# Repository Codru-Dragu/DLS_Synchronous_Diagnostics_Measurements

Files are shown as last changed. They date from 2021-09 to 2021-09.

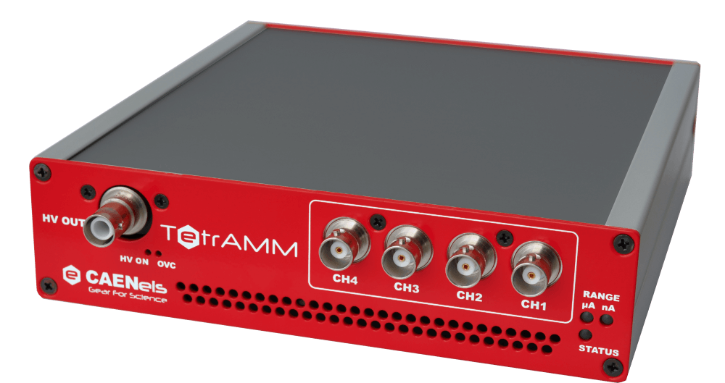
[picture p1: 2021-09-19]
Software Package/src/TetIMG.png

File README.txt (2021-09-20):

READ ME FILE for X-Ray Diagnostics Triggering system ofr DLS Diagnostics Team
Created by Summer Student 2021, Codrutza Dragu, University of Oxford

The hardware and software elements of the trigger are in their respective foler. A PDF help guide to both is located in the main directory, with the order of the GUI execution and what each file does. A general overview of the project is as given below:

This project is centered around helping the Diagnostics team acquire better data during their beamline vibrations analysis. This is done through a two-fold system, consisting of a ‘button-press’ hardware element to synchronously trigger the diagnostics hardware on the beamline, and a software package to fix any issues during data acquisition, and provide a user-friendly analysis interface. The system was tested on the i18 beamline in late June, and approximately 7hours worth of synchronous data was acquired and analyzed. The graphs produced at the end of the experiment indicate possibly uncorrelated vibrations coming from the horizontal focusing mirrors closest to the sample.

An issue many beamlines face, and one that affects the quality of the data acquired on the beamline, is if there are significant unwanted vibration present during beam time. These vibrations could be internal and come from the optical elements along the beamline, or from elements in the ring. They could even be external and come from overhead motion or from the air conditioning system. Identifying the source of unwanted vibration is critical in maintaining the quality of the beamline and the stability of the beam. Use of the diagnostics hardware present on the beamline allows data to be taken at beamline positions, and compared to determine whether there is uncorrelated motion present between the different acquisition devices, and if so, then further identification of the component causing the vibration. To accurately determine non-correlated motion, data should be acquired synchronously across all the hardware. The current limitation is that the EPICS interface controlling the hardware allows only manual acquisition for each hardware, and has no way to coordinate grabbing data from multiple hardware at the same time. The scope of this project is to produce a physical trigger system to control the hardware, and a software package that allows the trigger experiment to be monitored and has post-experiment Fourier analysis capabilities. 

The User Manual is porvided as the 'Help Guide' file and provides intructions and information about both the hardware and software packages.
More information and the results of the data anlysis from the i18 beamline experiemnt is available in the SummerStudent 2021 report document

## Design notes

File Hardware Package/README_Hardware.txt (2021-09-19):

This is the hardware portion of the project. It consits of the codes for a sender (Userside Arduino) and reciever (Midbox Arduino) as well as enclosures for the circuits required

STL for Trigger Enclosure Summary:
	
1 x UserSide_Box - the box for the control room arduino
	
1 x Midbox_Box - the box for the midbox arduino

1 x MidBox_Lid - lid for midbox box
	
1 x UserSide_Lid - lid fo userside box
	
1 x Userside_Cableholder - to secure the ethernet cable from the userside arduino box

4 x Midbox_Clip - Spacers to mount the midbox box. Print 2 extra (2+2) in case there are any drilling mishaps
	
1 x CamAdapt  - Adaptor for the Manta cam. Print for however many cameras there are. In our experiment, there was 1

2 x ActualTetAdapt - Adaptor for the Tetramm. Print for however many cameras there are. In our experiment, there waere 2
	
3 x Adapt_Lid - Lid for the TetrAMM and Camera Adaptor Boxes. Print for however many boxes there are. In our experiment, there were 3

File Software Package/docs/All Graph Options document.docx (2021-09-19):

All Graph options document

# Options Values

# Analysis Options:

# 0: DFT

# 1: CSP

# 2: CSP Normalised (Relative)

# Graph Options:

# 0: Plot X graph

# 1: Plot Y graph

# 2: Plot both X and Y graphs on the same plot

# Hardware options

# 0: A specific hardware - will be prompted to put the hardware name as well

# 1: A few select hardware - will be prompted to select which ones

# 2: All the hardware available

# Capture options

# 0: A specific capture - will be prompted to put which file is wanted

# 1: A range of captures unaveraged - will be prompted to put the range of files wanted

# 2: A range of captures averaged - will be prompted to put the range of files wanted

# 3: All files (this comes averaged by default)

# 4: All files average ONLY

# Stacked options

# 0: nonstacked

# 1: stacked

Different Graph Options and Corresponding Graph types:

(Alphabetical indexing scheme used in the Analysis_Grapher.py code file, and when deciding the kind of graph specified by the user checkbox options in Set_Up_Diagnostics_Hybrid.py)

A – Single Plot, Single Position, Single Hardware

B – Single Plot, Single Position, Multiple Hardware

C – Single Plot, Double Position, Single Hardware

D – Single Plot, Double Position, Multiple Hardware

E – Multiple Plot, Single Position, Single Hardware (DOES NOT EXIST)

F – Multiple Plot, Single Position, Multiple Hardware

G – Multiple Plot, Double Position, Single Hardware

H – Multiple Plot, Double Position, Multiple Hardware

Graph Display Options Based on Checkbox Choice

Analysis Options | Graph Options | Hardware Options | Stacked Option | Capture Options:
| | | | 0 (one capt) / 4 (only average displayed) | 1 (range) | 2 (range avg) | 3 (all)

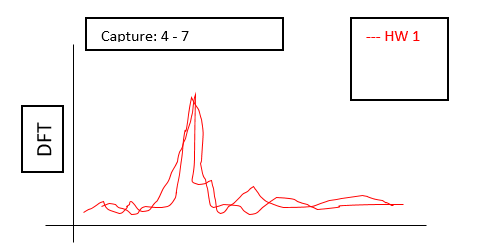
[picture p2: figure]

0 (DFT) A | 0 (x) 1 (y) (could be either) | 0 (1 hw) | 0
0 (DFT) | 0 (x) 1 (y) (could be either) | 0 (1 hw) | 1 | X | X | X | X

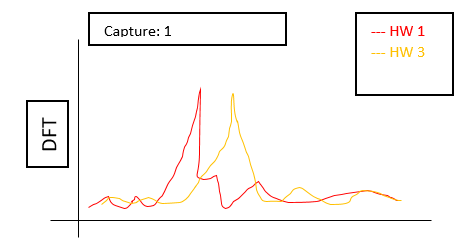
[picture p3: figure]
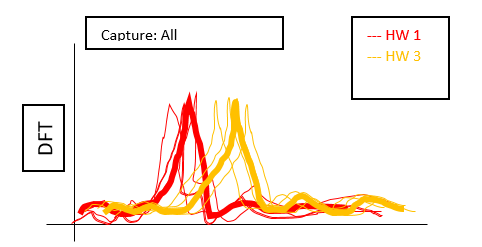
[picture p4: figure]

0 (DFT) B | 0 (x) 1 (y) (could be either) | 1 (more hw) | 0

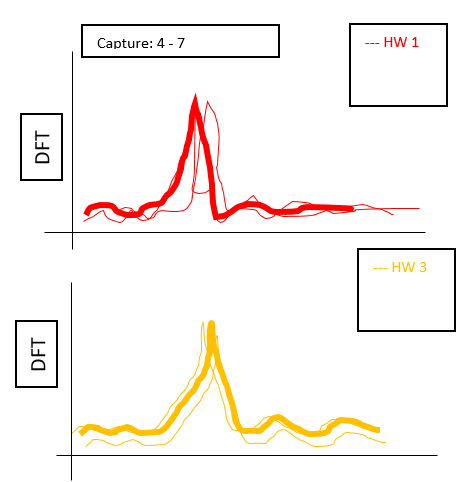
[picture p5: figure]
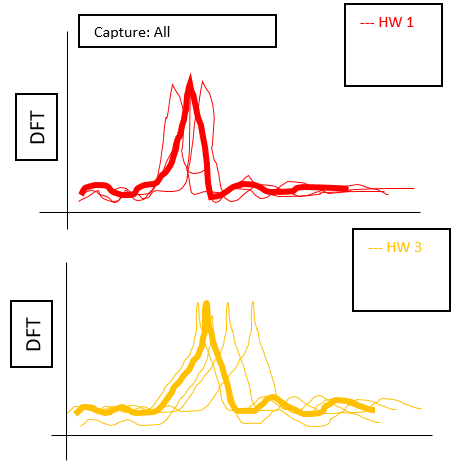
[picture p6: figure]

0 (DFT) F | 0 (x) 1 (y) (could be either) | 1 (more hw) | 1

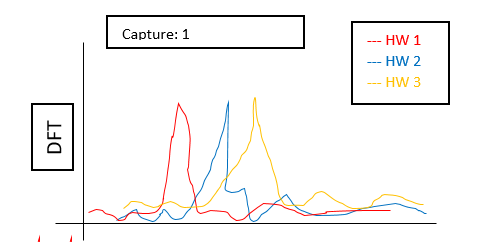
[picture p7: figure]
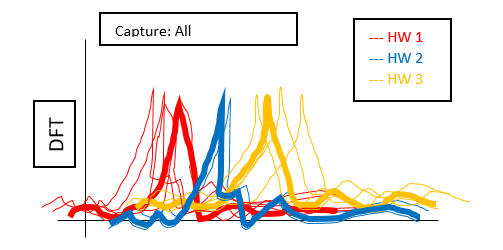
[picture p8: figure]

0 (DFT) B | 0 (x) 1 (y) (could be either) | 2 (all hw) | 0

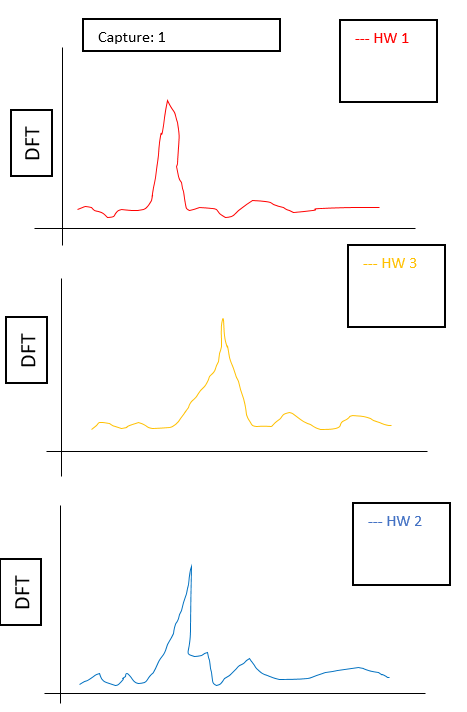
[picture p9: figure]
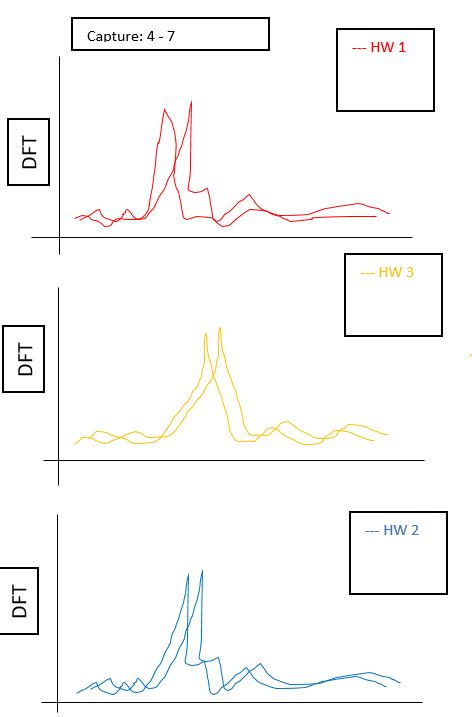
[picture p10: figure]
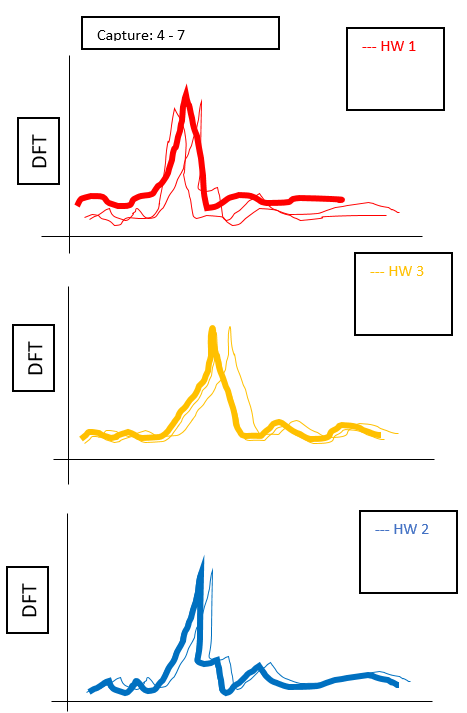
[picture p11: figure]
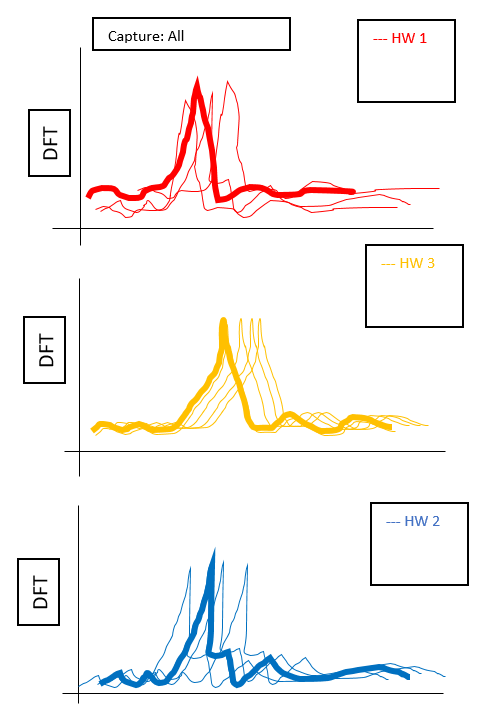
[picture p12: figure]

0 (DFT) F | 0 (x) 1 (y) (could be either) | 2 (all hw) | 1

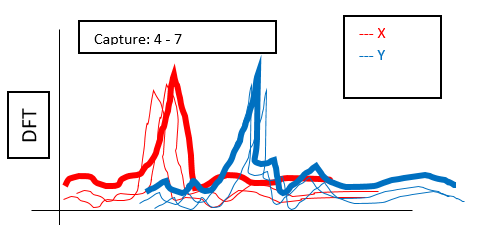
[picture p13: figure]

0 (DFT) C | 2 (both) | 0 (1 hw) | 0

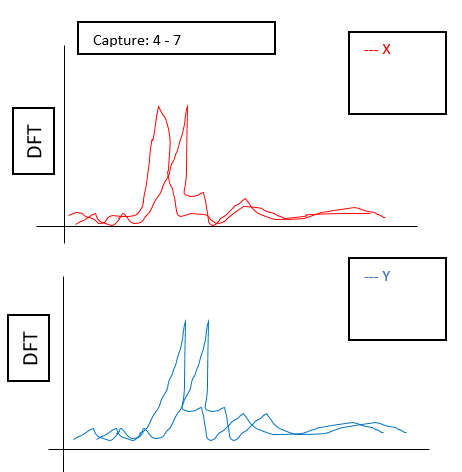
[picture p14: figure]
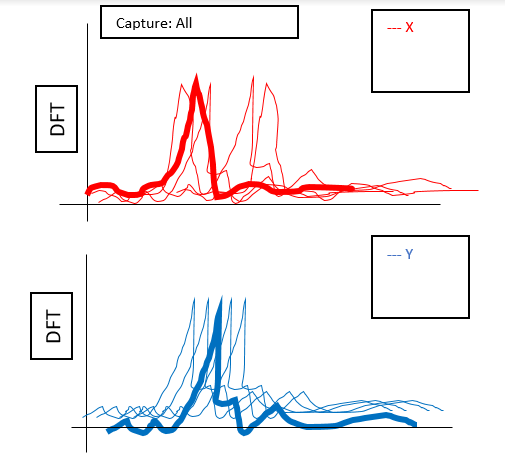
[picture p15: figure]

0 (DFT) G | 2 (both) | 0 (1 hw) | 1

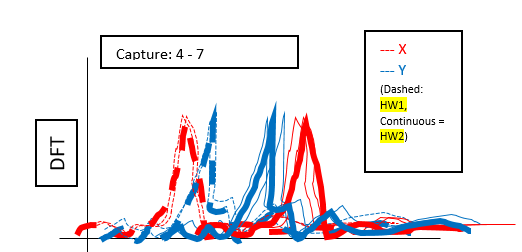
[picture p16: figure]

0 (DFT) D | 2 (both) | 1 (more hw) | 0

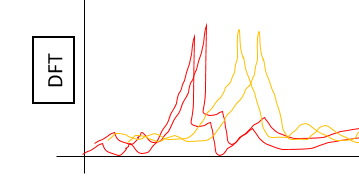
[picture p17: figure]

0 (DFT) H | 2 (both) | 1 (more hw) | 1 | X Data: Y Data: | X Data: Y Data: | X Data: Y Data: | X Data: Y Data:

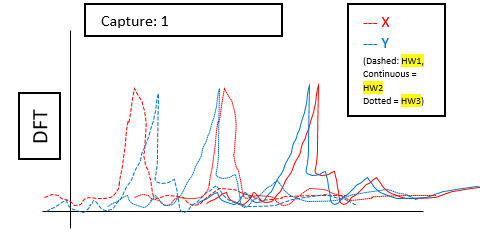
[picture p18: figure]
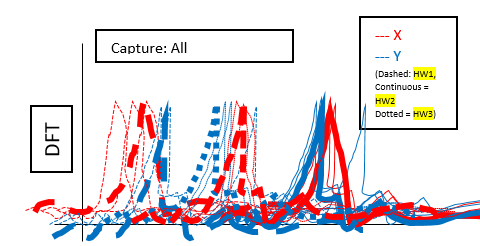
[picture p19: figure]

0 (DFT) D | 2 (both) | 2 (all hw) | 0

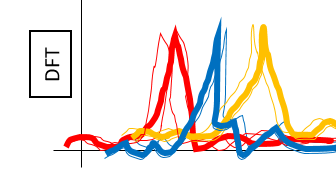
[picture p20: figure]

0 (DFT) H | 2 (both) | 2 (all hw) | 1 | X Data: Y Data: | X Data: Y Data: | X Data: Y Data: | X Data: Y Data:

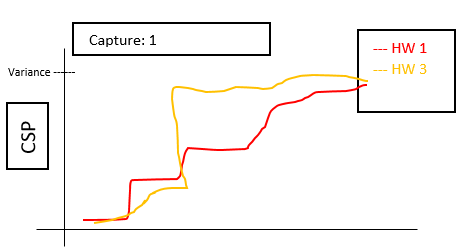
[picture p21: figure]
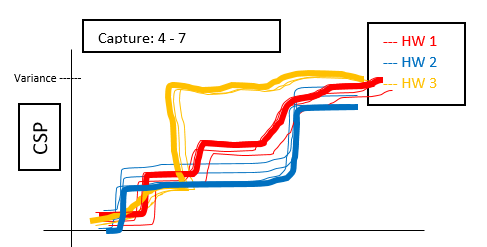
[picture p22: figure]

1 (CSP) | --- | --- | --- | Same Graph layout and orientation as the DFT graphs, only that the graph shape now looks like this:

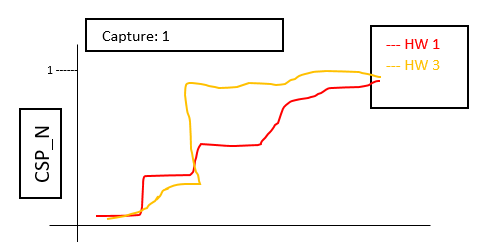
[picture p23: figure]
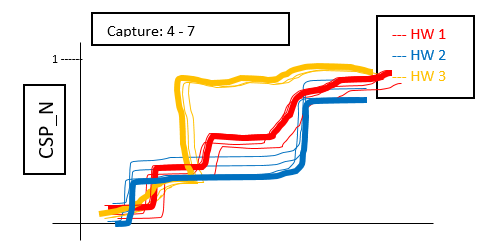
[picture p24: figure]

2 (CSP_N) | --- | --- | --- | Same Graph layout and orientation as the DFT graphs, only that the graph shape now looks like this:

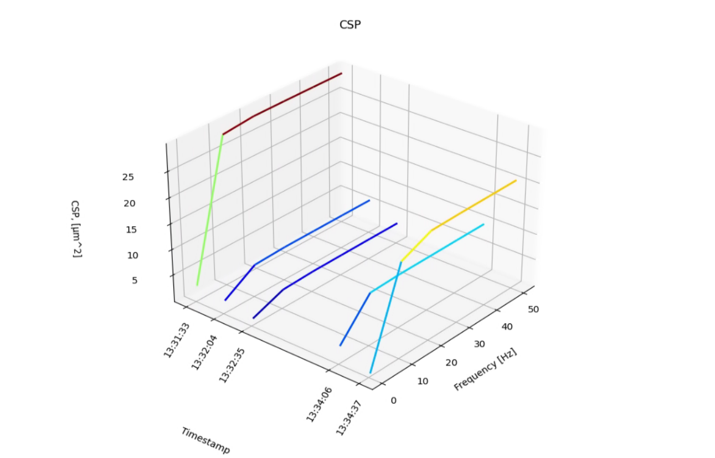
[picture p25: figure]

4 (Waterfall) | --- | --- | --- | Waterfall plot can only produce plot for one hardware, one position, for either all the files or a range of files

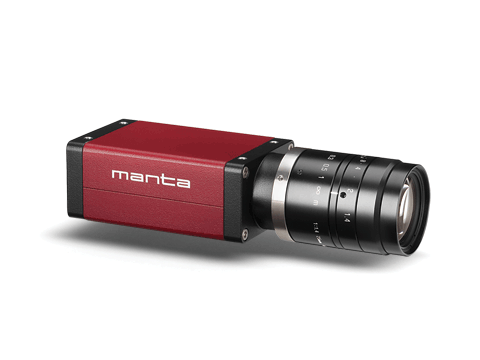
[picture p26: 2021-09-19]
Software Package/src/CamIMG.png

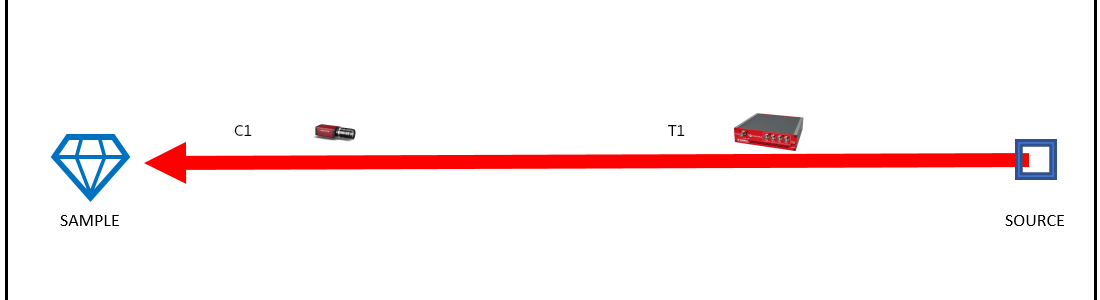
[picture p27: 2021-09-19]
Software Package/src/BeamSchemAnno.png

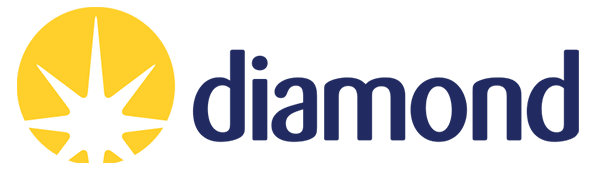
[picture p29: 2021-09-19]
Software Package/src/Diamond.png

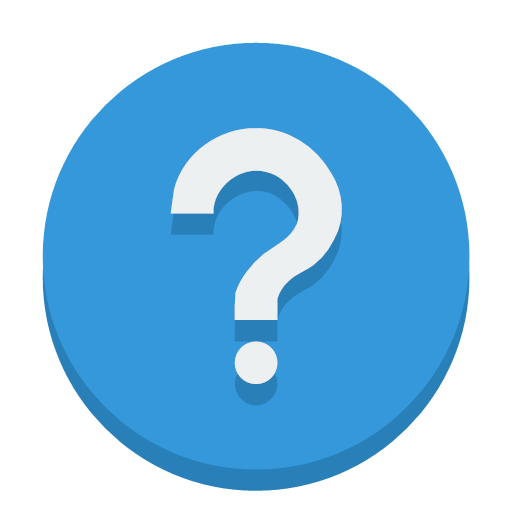
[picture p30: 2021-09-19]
Software Package/src/help.png

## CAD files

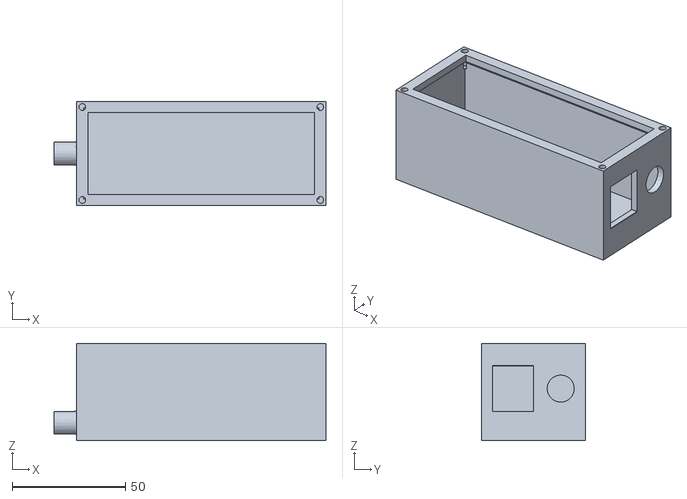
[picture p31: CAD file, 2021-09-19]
Hardware Package/enclosures/CamAdapt.stl
120.0 x 46.0 x 43.0

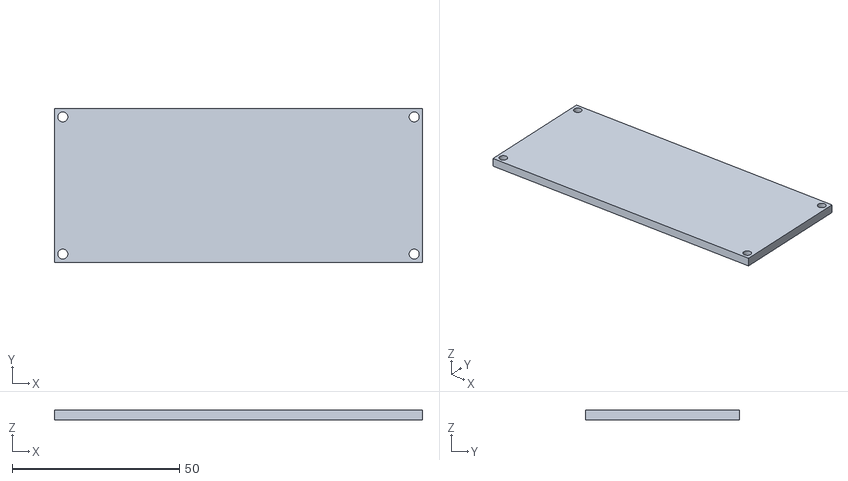
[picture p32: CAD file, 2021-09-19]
Hardware Package/enclosures/Adapt_Lid.stl
110.0 x 46.0 x 3.00

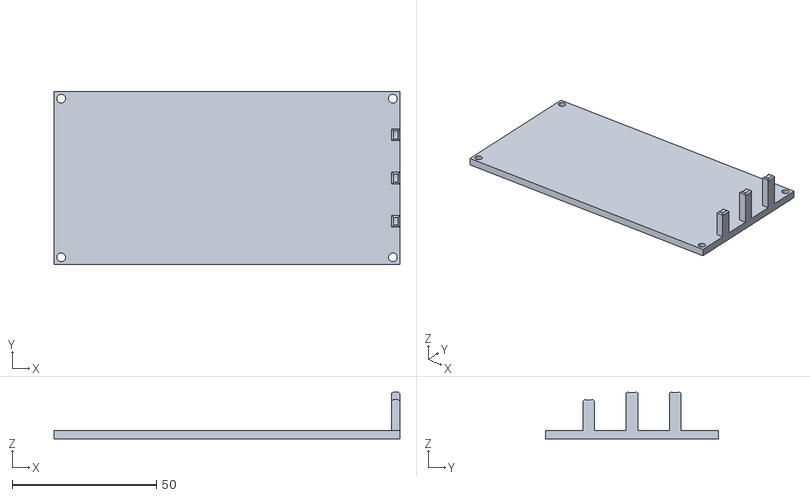
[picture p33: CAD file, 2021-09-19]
Hardware Package/enclosures/Userside_Lid.stl
120.0 x 60.0 x 16.3

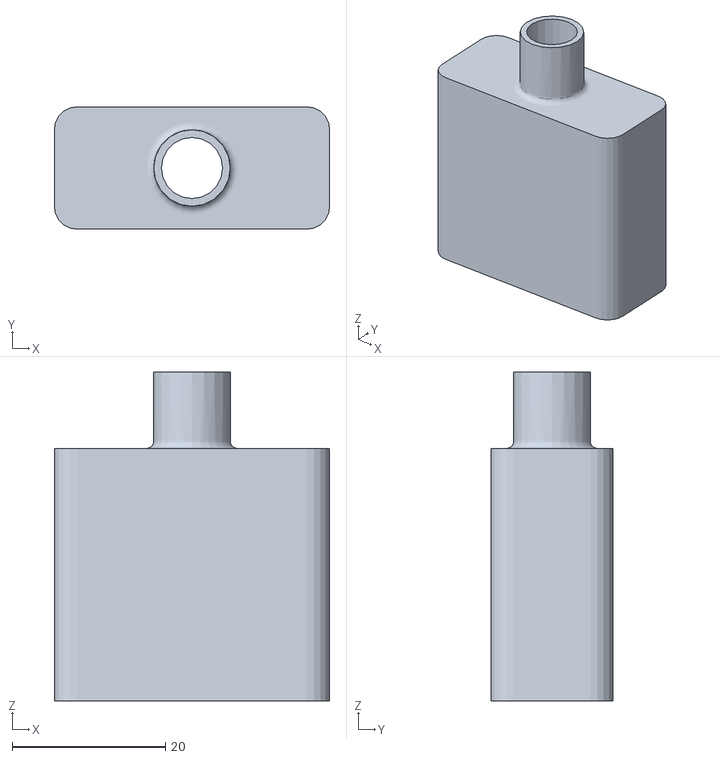
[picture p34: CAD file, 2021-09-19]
Hardware Package/enclosures/Userside_CableHolder.stl
36.0 x 16.0 x 43.0

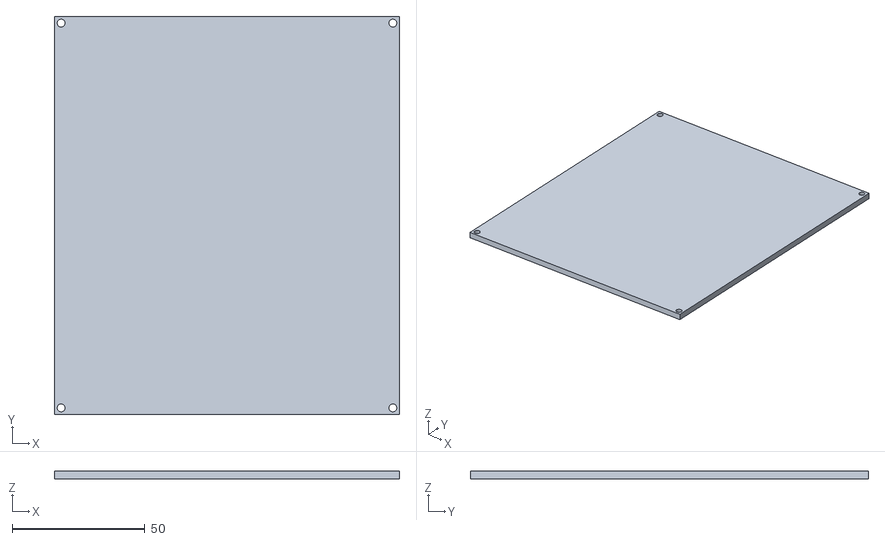
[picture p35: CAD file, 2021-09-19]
Hardware Package/enclosures/MidBox_Lid.stl
130.0 x 150.0 x 3.00

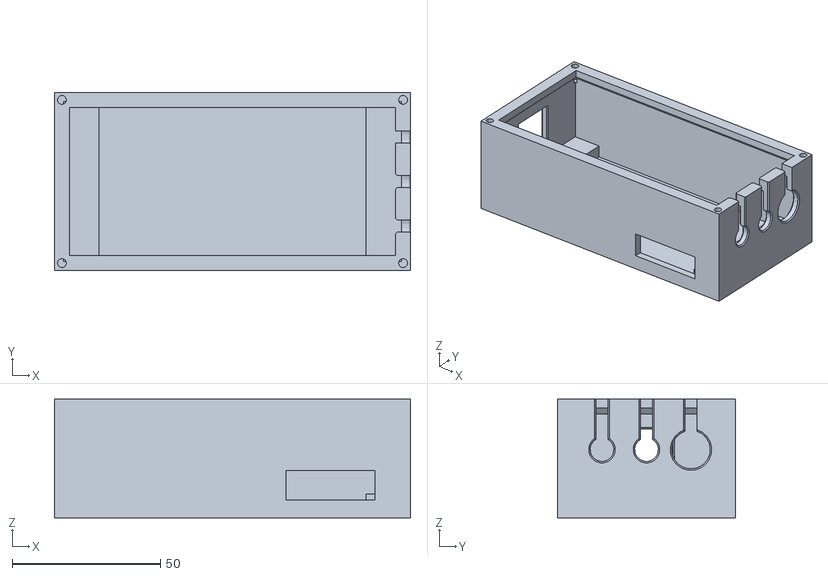
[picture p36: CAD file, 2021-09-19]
Hardware Package/enclosures/Userside_Box.stl
120.0 x 60.0 x 40.0

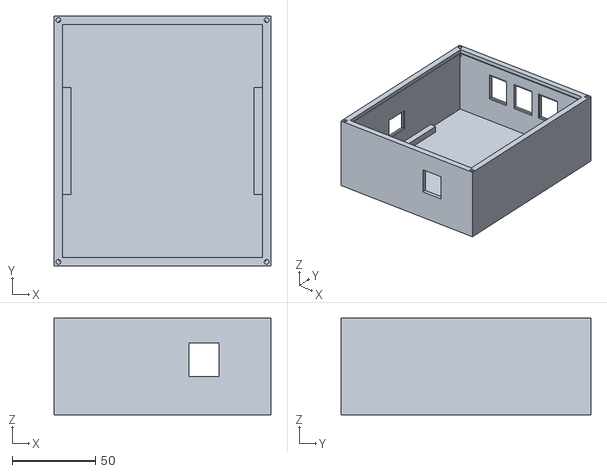
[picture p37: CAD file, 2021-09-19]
Hardware Package/enclosures/Midbox_Box.stl
130.0 x 150.0 x 58.0

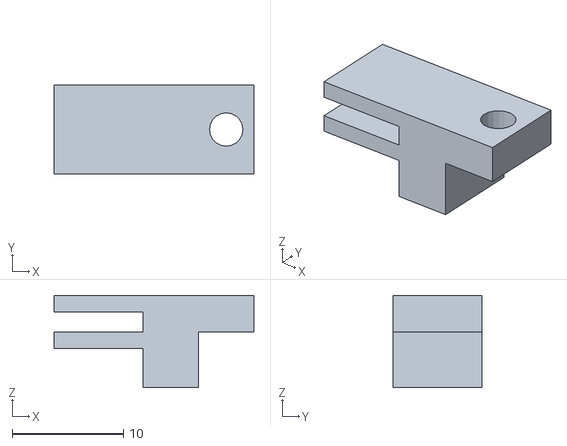
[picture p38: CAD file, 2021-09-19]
Hardware Package/enclosures/MidBox_Clip.stl
18.0 x 8.00 x 8.30

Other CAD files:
Hardware Package/enclosures/ActualTetAdapt.stl

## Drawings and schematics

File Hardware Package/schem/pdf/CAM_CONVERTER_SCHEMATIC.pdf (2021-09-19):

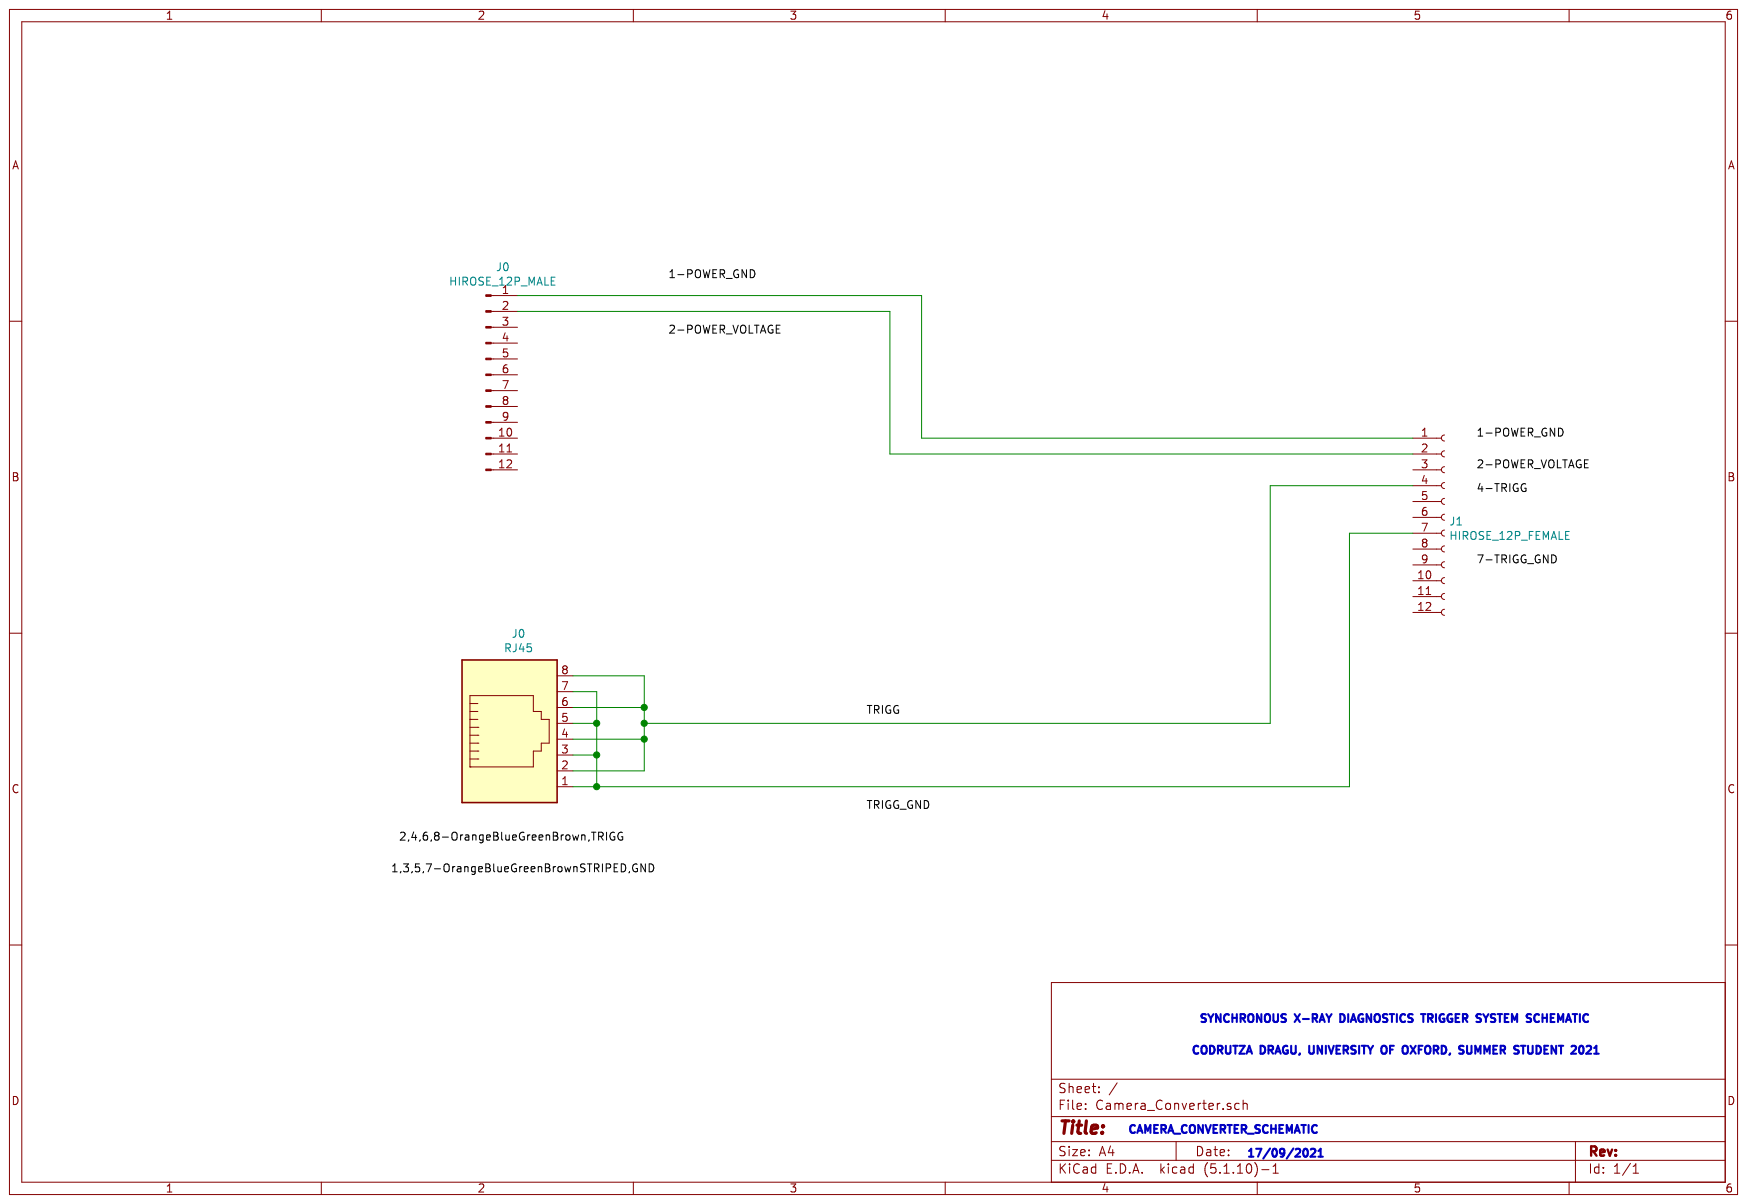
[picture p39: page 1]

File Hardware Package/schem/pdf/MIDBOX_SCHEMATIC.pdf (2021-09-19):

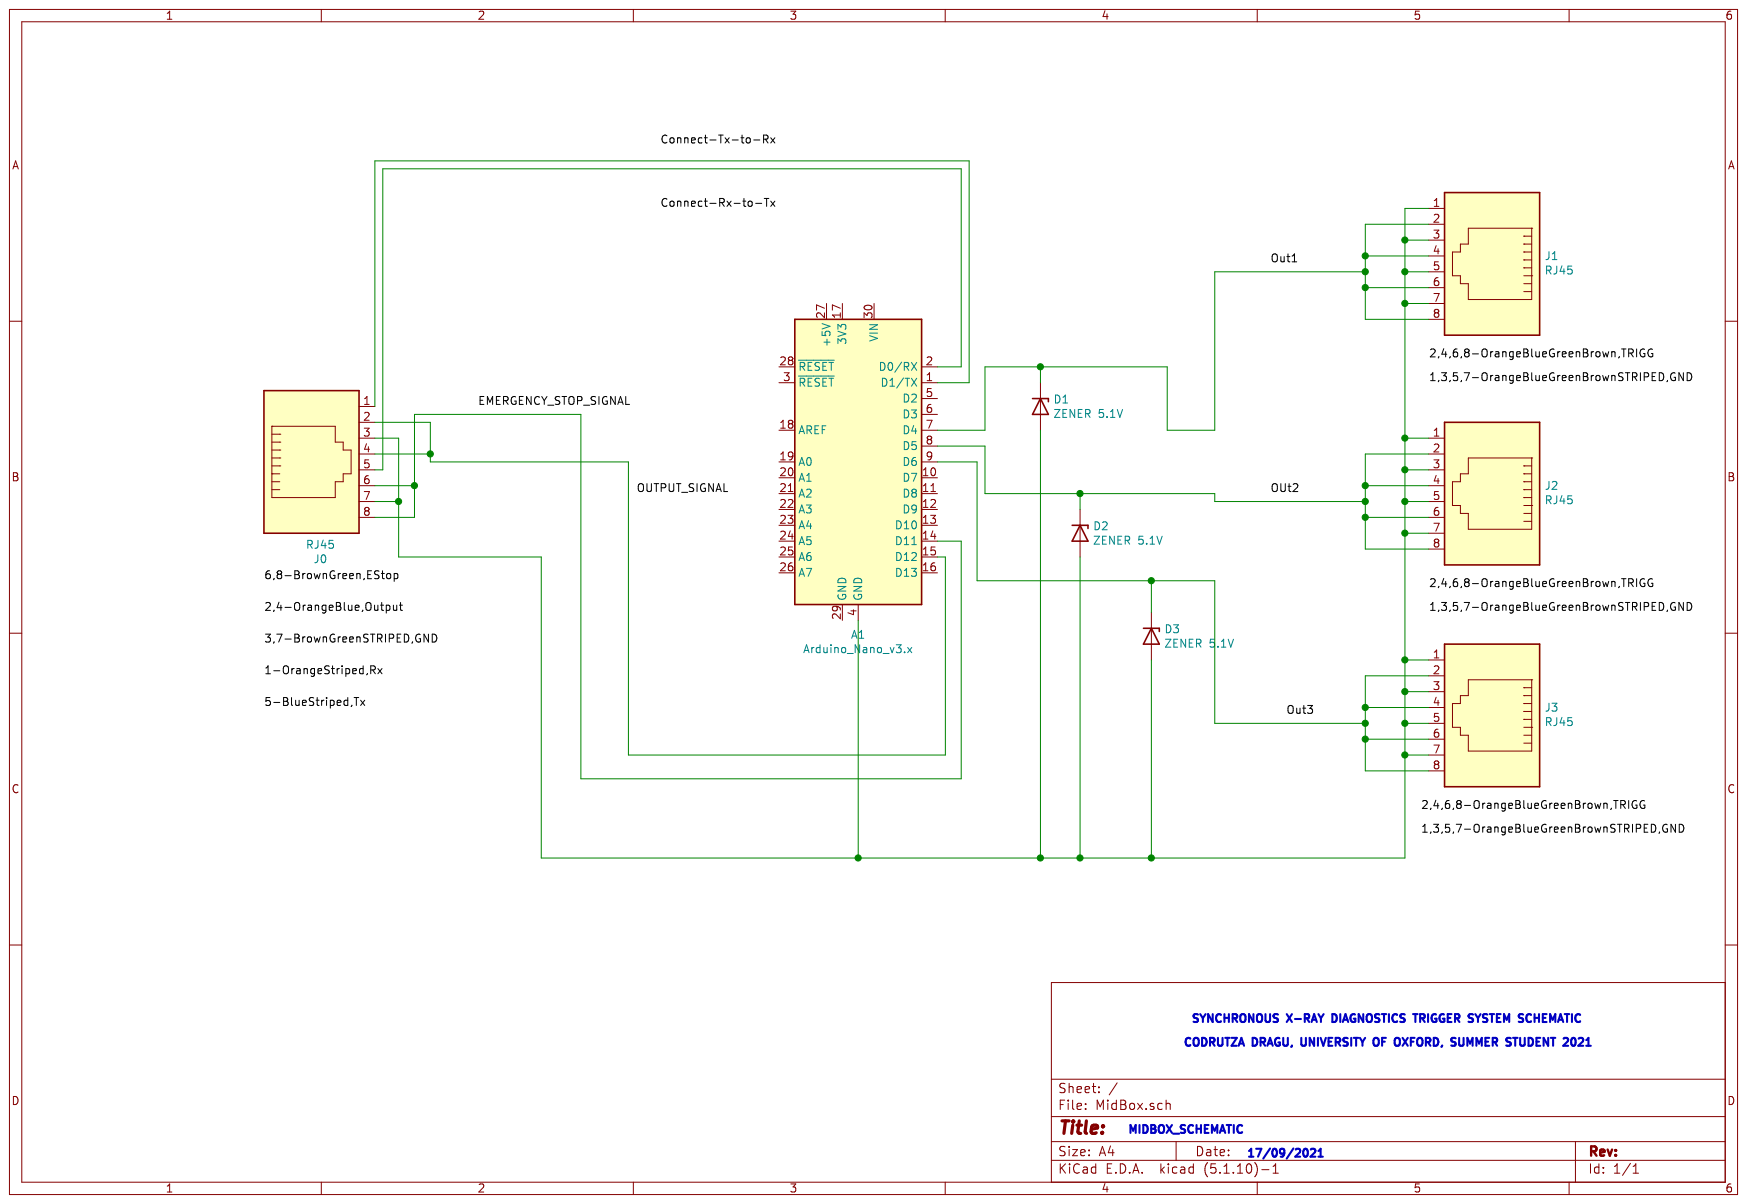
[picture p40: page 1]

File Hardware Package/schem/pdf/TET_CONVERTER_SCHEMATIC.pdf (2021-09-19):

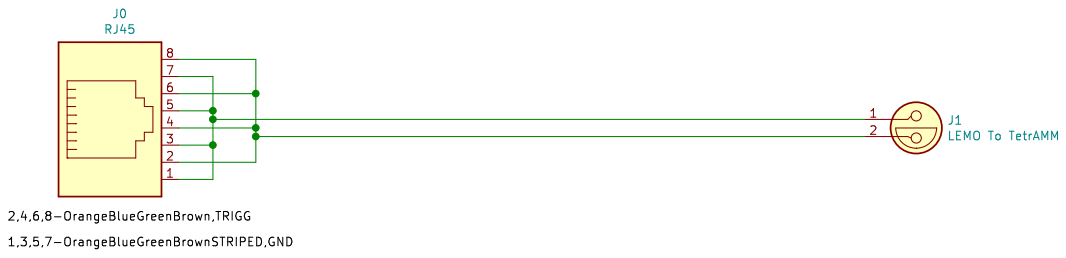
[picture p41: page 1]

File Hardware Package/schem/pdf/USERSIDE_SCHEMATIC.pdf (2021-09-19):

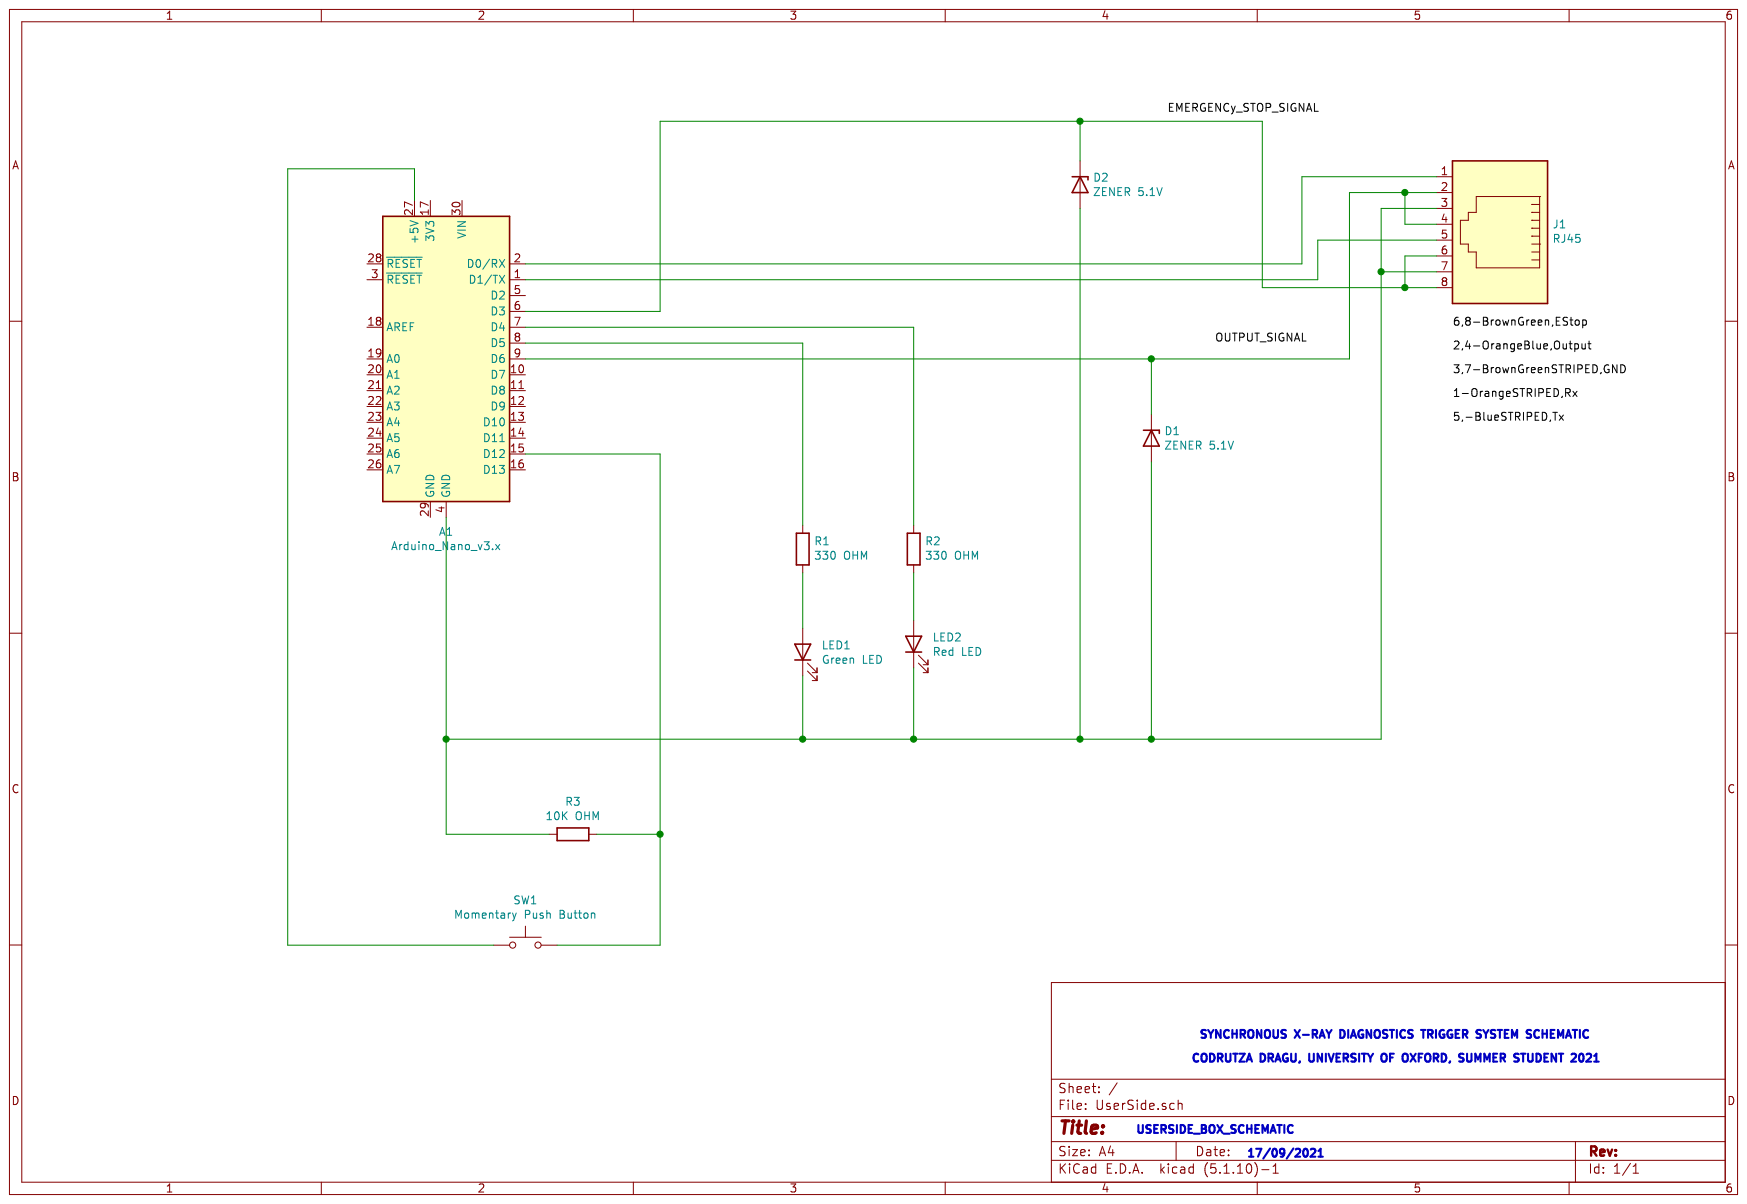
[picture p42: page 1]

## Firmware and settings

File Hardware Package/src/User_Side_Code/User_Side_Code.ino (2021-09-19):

// Initialise and declare variables
const int bttnPin = 12;    // The toggle button is attached to this pin - PORTC
const int startLed = 5;  // Led to indicate that the process has started - PORTD
const int stopLed = 4;    // Led to indicate that the process has not started / has stopped - PORTD
const int output = 6;     // Send the ouput trigger signal - PORTD
const int e_output = 3; // Send Emergency stop signal - PORTC

int bttnState = LOW; // Button state tracker, low if not pressed, high if pressed
int startState = -1; // Start indicator LED state tracker, negative if off, positive if on
int stopState = 1;   // Stop indicator LED state tracker, negative if off, positive if on
int triggStart = -1; // Trigger start tracker

long lastDebouncerTime = 0; // last time the output pin was toggled
long debounceDelay = 600;   // the debounce time; increase if the output flickers

int activ_period = 1000; // Length of blink


// ************************************************************

// TO BE EDITED BY USER // --> EG. collect 10 seconds of data every 20 seconds
unsigned long interval_time = 20000; // Length of time between data collection intervals // EG. 20 seconds // KEEP AT LEAST 20S (30S)
// This will be transmitted to the other arduino (to communicate via serial port)
unsigned long gate_interval = 10000; // Length of time for which the trigger on signal is held (length of time for which you want to acquire data) // EG. 10 seconds
// MODES
int mode = 1; // Choice of Mode: 0 -> One off trigger, 1 -> Conitnuous trigger

// ************************************************************


// Undeitable from other Arduino (constant - if you change it here you must also change it in the other code.)
unsigned long buffer_time = 500; // Buffer to make sure the last captures are not clipped (1.5 seconds)
unsigned long total_delay = 30.5; // This delay was determined experimentally

// Wait between blinks - uneditable 
unsigned long wait_period = (interval_time + buffer_time + total_delay + gate_interval)-activ_period;  // Pause between blinks minus the interval time (need to minus the active period as the signal is on from the active period and this only adds time (as in, the active period time is already accounted for, do not add it twice)))
unsigned long time_now = 0; // The current time

int a = 1; // Infinted while loop variable - do not edit.

// Serial Check
int did_ser = 0; // Int to check if the gate value has already been sent by serial connection
char numarr[7]; // Use 7 instead of 6 as 6 produces weird characters at the end for some reason, stores the char version of the gate signal

// Function to prepare the numarr array
void preprint(unsigned long tosplit)
{
  // Assuming the longest gate time you could possibly want was 2 minutes (120000 milisecs)
  // That is 6 digits, so send each digit as part of an array and complete the 6 available slots:
  // First, set all the numarr spaces to 0:
  numarr[0] = '0';
  numarr[1] = '0';
  numarr[2] = '0';
  numarr[3] = '0';
  numarr[4] = '0';
  numarr[5] = '0';

  // Set the count
  int count = 6;

  while (count >= 0)
  {
    if (tosplit != 0)
    {
      int digi = tosplit % 10; // Get the last digit
      char c = '0'+digi; // convert it to char - need the '0'
      numarr[count-1] = c; // add it to the end of the array
      tosplit = tosplit/10; // Divide tosplit by 10 
    }
    count = count - 1; // Decrease count until the whole array is filled with the number and leading zeroes
  }
// The numarray has been made  
}



void setup() {
  
  // Set the pin modes
  pinMode(startLed, OUTPUT); // Start LED
  pinMode(stopLed, OUTPUT);  // Stop LED
  pinMode(bttnPin, INPUT);   // Button Pin 
  pinMode(output, OUTPUT);   // Signal sender
  pinMode(e_output, OUTPUT); // Emergecy Signal Stop
 
  digitalWrite(stopLed, HIGH); // Trigger is off initially, so set the Stop LED on
  digitalWrite(e_output, HIGH); // Trigger is off initially, so set the Stop LED on

  preprint(gate_interval); // Convert the long gate_interval into a sendable char array
  Serial.begin(9600);
}

void loop() {

  // Before everything happens, check if the set up has been done or not:
  if(did_ser == 0) // the serial set up has not been done, go here:
  {
     while(!Serial.available()) // While no handshake signal is being recieved from the midbox arduino
   { // Send the gate value accross serial
      Serial.write(numarr,6);
      delay(500);
   }
   // When the handshake signal has been recieved, it breaks the loop and ends the serial connection
  Serial.end();

  // Toggle serial set up done marker
  did_ser = 1;
  }

  // After the Serial set up is done, resume normal looping 
  
  else
  {
  
  bttnState = digitalRead(bttnPin); // check button state
  //Serial.println( String( "Button input (signalState) = " ) + bttnState);
  
  // Filter out noise by setting a time buffer
  if (( millis()-lastDebouncerTime )> debounceDelay)
  {    
    // If button pressed, toggle the led indicators
    if ((bttnState == HIGH)&&(startState < 0))
    {    
      PORTD = B01100000; // Start LED High, Output High, Stop LED Low, EMergency signal low
      startState = - startState;    // Record change in LED state
      lastDebouncerTime = millis(); // Set the debouncer time
      triggStart = 1;
    }    
    
    else if ((bttnState == HIGH)&&(startState > 0))
    {    

      PORTD = B00011000; // Start LED Low, Output Low, Stop LED High, Emergency Signal High
      startState = - startState;    // Record change in LED state
      lastDebouncerTime = millis(); // Set the debouncer time
      triggStart = -1;
    }

    // If the trigger start signal is sent then start acquisition by sending the output signal
    if ((triggStart == 1))
    {
      // Get the current time
      time_now = millis();
      
      while(millis() < time_now + activ_period) // While the time is less than the active period of the LED
      {
        PORTD = B01100000; // Start LED High, Output High, Stop LED Low, EMergency signal low
        if(digitalRead(bttnPin) == 1) // Break if the button press detected (reset mode)
        {
          break;
        }       
      }
      

      // For the one-off mode specifically, once the 1 second active period is up, turn off the output signal but keep the led's on
      // The one off mode will be stopped by default (red light on) then when pressed filicker red and green and remain in the red green state wihtout sending another trigger
      // Then when pressed again, will go back to the default stopped red state. Therefore, between triggers, the button should be pressed twice- onece to reset (red mode) and then to trigger gain (red green mode)
      if(mode == 0)
      {
        while(a == 1) // infinite while loop to stop sending conitnuous signals
      {
        PORTD = B00110000; // Start LED Low, Output low, Stop LED high, Emergency Signal high
        if(digitalRead(bttnPin) == 1) // Break if button press detected (reset mode)
        {
          break;
        }  
      }
  
      }
      // For the continuous mode:
      else 
      {
        time_now = millis();
        while(millis() < time_now + wait_period) // Check if the current time is less than the waiting period or not
        {
        PORTD = B00000000; // Start LED Low, Output Low, Stop LED Low, Emergency Signal low
        if(digitalRead(bttnPin) == 1) // Break if button press detetcted (reset mode)
        {
          break;
        }  
      }
        
        
        
      }
      

      
    }
   }
 }
}

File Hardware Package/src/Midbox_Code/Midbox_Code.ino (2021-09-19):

// Initialise and declare variables
#define signalPin 12 // The toggle button is attached to this pin - PORTC
#define estopPin 11  // The emergency stop signal - PORTC  
#define out1 6       //  - PORTD // TET
#define out2 5       // - PORTD // TET
#define out3 4       // - PORTD // CAM

int signalState = LOW; // Button state tracker, low if not pressed, high if pressed

// To be read from the userside arduino
unsigned long gate_time; // Length of gate trigger signal that you want (how long you want to acquire data for)

// Constant delays and buffers
int buffer_time = 500; // Length of add on to gate trigger to capture last frame --> add on 2 seconds
int cam_delay = 30.5; // experimentally determined delay 

unsigned long time_now = 0; // Current time
int start_gate = -1; // Boolean to record whether this is the first start or not

unsigned long gate;

// Serial Check
char numarr[7]; // Stores the char version of the unsigned long gate_time

void setup() {
  
  // Set the pin modes
  pinMode(out1, OUTPUT); // Output to hardware (1,2 and 3)
  pinMode(out2, OUTPUT);  
  pinMode(out3, OUTPUT);   
  pinMode(signalPin, INPUT);  // Input from user side
  pinMode(estopPin, INPUT);  // Input from user side

  // All off
  PORTD = B00000000;

  // Serial start 
  Serial.begin(9600);
}

void loop() {
  
  signalState = digitalRead(signalPin); // check button state
  
  if (signalState == HIGH) // if the signal is high 
  {
    time_now = millis();
    while( millis() < (time_now + gate) )
    {
      PORTD = PORTD | B00010000;; // Start only output 3 (pin 4) --> where the camera is connected to

      if(millis()>(time_now + cam_delay))
      {
       PORTD = PORTD | B01110000; // Set all to outputs to on, using or logic to not affect the other outputs to produce a uniform square wave 
      }

      if (digitalRead(estopPin) == 1)
       {
         break;  
       }
    }

    signalState = digitalRead(signalPin); // check button state
    Serial.begin(9600);
  }
  
  if (signalState == LOW) // Keep the outputs off and listen for the Serial port
  {
       PORTD = B00000000; // All off 
       while(Serial.available()) // While there is something being sent 
       {
       int sigstate = digitalRead(signalPin); // check button state
       if(sigstate == HIGH)
       {
        Serial.end();
        break; // break the loop if the signal state is high
       }
       Serial.readBytes(numarr,6); // Read the serial data and store it
       Serial.write('1'); // Send this twice to terminate the other Arduino
       Serial.write('1'); // Send this twice to terminate the other Arduino
       gate_time = atoi(numarr);
       gate = gate_time + buffer_time + cam_delay; // total gate length, not editable
       Serial.end();
       } 
  }

}
